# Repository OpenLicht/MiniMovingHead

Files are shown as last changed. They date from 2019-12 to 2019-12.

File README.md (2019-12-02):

# Moving Head

## Pinout

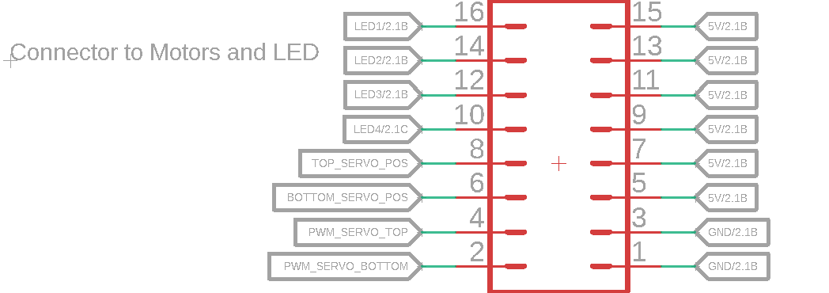
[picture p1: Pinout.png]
Pinout


## Protocol
Length is 3 bytes, command byte followed by two value bytes  
| command | value(high) | value(low)|

### Example
Set led_0 brightness to 100%  
Bytes to send: 0x70 0x00 0x64

## State select
|Command | State|
|---|---|
|0x91 | Manual movement|
|0x92 | Position regulation|

## Manual movement
|Command | Value | Action |
|---|---|---|
|0x41 | 0x00 | move bottom servo clockwise|
|0x42 | 0x00 | move bottom servo anticlockwise|
|0x45 | 0x01 ... 0x10 | set bottom servo speed [1 - 10]|
|0x51 | 0x00 | move top servo anticlockwise|
|0x52 | 0x00 | move top servo clockwise|
|0x70 | 0x00 ... 0x64 | set led_0 brightness [0 - 100 %]|
|0x71 | 0x00 ... 0x64 | set led_1 brightness [0 - 100 %]|
|0x72 | 0x00 ... 0x64 | set led_2 brightness [0 - 100 %]|
|0x73 | 0x00 ... 0x64 | set led_3 brightness [0 - 100 %]|
|0x90 | 0x00 | stop bottom servo|

## Position regulation
|Command | Value | Action|
|---|---|---|
|0x60 | 0x00 ... 0x168 | move bottom servo to position [0 - 360°]|
|0x61 | 0x00 ... 0xB4 | move top servo to position [0 - 180°]|
|0x70 | 0x00 ... 0x64 | set led_0 brightness [0 - 100 %]|
|0x71 | 0x00 ... 0x64 | set led_1 brightness [0 - 100 %]|
|0x72 | 0x00 ... 0x64 | set led_2 brightness [0 - 100 %]|
|0x73 | 0x00 ... 0x64 | set led_3 brightness [0 - 100 %]|

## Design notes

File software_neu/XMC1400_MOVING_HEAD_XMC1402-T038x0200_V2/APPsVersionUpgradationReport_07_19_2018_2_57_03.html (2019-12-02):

### DAVE CE Project Migration Report

#### APPs Upgrade to latest product version

Project name : XMC1400_MOVING_HEAD_XMC1402-T038x0200_0_Upgraded_0Date & Time : 07/19/2018 2:57 PM

Migration Log & Status

Project upgrade option will create a new project named with latest version of:

• APPs
• Startup folder
• Libraries folder
• linker_script.ld

All other settings and source files will be copied from this project

APPs Upgrade.. Started

Checking APP versions, found 5 APPs to migrate to higher versions

APPs Upgrade.. Completed

Getting solution from solver.. Successful

Code generation.. Successful

Build.. Successful

List of APPs
APP Name | | Message
CCU4_SLICE_CONFIG [v4.0.8] | Errors:0 Warnings:0 Info:0 | Higher version 4.0.16 found in Library store
CLOCK_XMC1 [v4.0.18] | Errors:0 Warnings:0 Info:0 | Higher version 4.0.20 found in Library store
CPU_CTRL_XMC1 [v4.0.6] | Errors:0 Warnings:0 Info:0 | Higher version 4.0.8 found in Library store
DIGITAL_IO [v4.0.16] | Errors:0 Warnings:0 Info:0 | No higher product version found in the Library store
GLOBAL_CCU4 [v4.1.12] | Errors:0 Warnings:0 Info:0 | No higher product version found in the Library store
GLOBAL_CCU8 [v4.1.12] | Errors:0 Warnings:0 Info:0 | No higher product version found in the Library store
I2C_MASTER [v4.1.18] | Errors:0 Warnings:0 Info:0 | Higher version 4.1.26 found in Library store
PWM [v4.1.10] | Errors:0 Warnings:0 Info:0 | No higher product version found in the Library store
UART [v4.1.8] | Errors:0 Warnings:0 Info:0 | Higher version 4.1.10 found in Library store

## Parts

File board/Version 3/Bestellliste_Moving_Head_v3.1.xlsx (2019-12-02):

Bauteile | Im Labor verfügbar? | Anzahl | Preis pro Stück | Kosten | Quelle |  | Nein
TPS71433DRVR | Nein | 1 | 0.648 | 0.6480 | https://www.mouser.de/ProductDetail/Texas-Instruments/TPS71433DRVR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 | 3.3V LDO U4 | Ja
GRM21B5C1H223FA01L 2,2nF/0,0022uF | Nein | 4 | 0.699 | 2.7960 | https://www.mouser.de/ProductDetail/Murata-Electronics/GRM21B5C1H223FA01L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 | C15,C17,C18,C19
C0805X225J4RECAUTO 2,2uF | Nein | 5 | 0.393 | 1.9650 | https://www.mouser.de/ProductDetail/KEMET/C0805X225J4RECAUTO | C2,C4,C6,C20,C7
C0805C475J9RACAUTO 4,7 uF | Nein | 1 | 0.402 | 0.4020 | https://www.mouser.de/ProductDetail/KEMET/C0805C475J9RACAUTO | C8 | Ja
:885012207098 100nF/0.1uF | Nein | 2 | 0.06 | 0.1200 | https://www.mouser.de/ProductDetail/Wurth-Electronics/885012207098 | C9,C10
CRL0805-JW-R300ELF 300 mOhm | Nein | 4 | 0.201 | 0.8040 | https://www.mouser.de/ProductDetail/Bourns/CRL0805-JW-R300ELF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 | R1,R2,R4,R8
BAT20JFILM dioden | Nein | 4 | 0.332 | 1.3280 | https://www.mouser.de/ProductDetail/STMicroelectronics/BAT20JFILM | D1,D3,D4,D5
24AA01T-I/OT | Nein | 1 | 0.18 | 0.1800 | https://www.mouser.de/ProductDetail/Microchip-Technology/24AA01T-I-OT?qs=JaP0%252bruNJH9QbK8hwgt6AQ== | EEPROM
105017-0001 USB Connector | Nein | 1 | 0.599 | 0.5990 | https://www.mouser.de/ProductDetail/Molex/105017-0001 | J1
20021111-00010T4LF Debug Connector | Nein | 2 | 0.533 | 1.0660 | https://www.mouser.de/ProductDetail/Amphenol-FCI/20021111-00010T4LF | J2
 | Nein |  |  | 0.0000 |  |  | Ja
LT3476EUHF#PBF LED TREIBER | Nein | 1 | 8.52 | 8.5200 | https://www.mouser.de/ProductDetail/Analog-Devices-Linear-Technology/LT3476EUHFPBF | LED Treiber
ERJ-PB3B4991V 4,99k ohm | Nein | 4 | 0.21 | 0.8400 | https://www.mouser.de/ProductDetail/Panasonic/ERJ-PB6B4991V | R9,R10,R11,R12
LG R971-KN-1 green | Nein | 1 | 0.096 | 0.0960 | https://www.mouser.de/ProductDetail/Inolux/IN-S85ATG | LED2
6ENF4422V 44.2kohm | Nein | 1 | 0.087 | 0.0870 | https://www.mouser.de/ProductDetail/Panasonic/ERJ-6ENF4422V | R13
ERJ-P6WF4701V | Nein | 2 | 0.484 | 0.9680 | https://www.mouser.de/ProductDetail/Panasonic/ERJ-P6WF4701V | R3
CRCW08050000Z0EAC 0 Ohm | Nein | 1 | 0.087 | 0.0870 | https://www.mouser.de/ProductDetail/Vishay/CRCW08050000Z0EAC | R16
CRCW080510K0FKEAC 10k Ohm | Nein | 2 | 0.046 | 0.0920 | https://www.mouser.de/ProductDetail/Vishay/CRCW080510K0FKEAC | R5/R6
ERJ-PB6B3302V 33k | Nein | 1 | 0.507 | 0.5070 | https://www.mouser.de/ProductDetail/Panasonic/ERJ-PB6B3302V | R7
F931C476MBAAJ6 | Nein | 1 | 0.599 | 0.5990 | https://www.mouser.de/ProductDetail/AVX/F931C476MBAAJ6 | C5 Tantalkondensator
KMR211GLFS | Nein | 1 | 0.296 | 0.2960 | https://www.mouser.de/ProductDetail/CK/KMR211GLFS | Taster
5V 2.1A Netzteil Power Adapter USB Charger EU Plug mit micro USB Kabel | Ja | 1 | 8.5 | Im Labor verfügbar | https://eckstein-shop.de/5V-21A-Netzteil-Power-Adapter-USB-Charger-EU-Plug-mit-micro-USB-Kabel | USB Netzteil
LZ2012M100WT - Hochfrequenzinduktivität, Oberflächenm., Baureihe MLZ, 10 µH, 350 mA, 0805 [Metrisch 2012] | Nein | 4 | 0.108 | 0.4320 | https://www.mouser.de/ProductDetail/TDK/MLZ2012M100WT000 | L3,L4,L5,L6
 | Nein |  |  | 0.0000
XMC1402T038X0200AAXUMA1 | Nein | 1 | 3.44 | 3.4400 | https://www.mouser.de/ProductDetail/Infineon/XMC1402T038X0200AAXUMA1/
BMD-340-A-R | Nein | 1 | 8.71 | 8.7100 | https://www.mouser.de/ProductDetail/Rigado/BMD-340-A-R
SML-H12V8TT86 | Nein | 1 | 0.428 | 0.4280 | https://www.mouser.de/ProductDetail/ROHM-Semiconductor/SML-H12V8TT86?qs=493kPxzlxfI59R5PYPQRxg%3D%3D
 | Ja |  |  | Im Labor verfügbar
 | Ja |  |  | Im Labor verfügbar
 | Ja |  |  | Im Labor verfügbar
ERJ-6ENF5100V 510 ohm | Nein | 1 | 0.087 | 0.0870 | https://www.mouser.de/ProductDetail/Panasonic-Industrial-Devices/ERJ-6ENF5100V | R17
ABM8W-20.0000MHZ-4-B1U-T3 | Nein | 1 | 0.525 | 0.5250 | https://www.mouser.de/ProductDetail/ABRACON/ABM8W-200000MHZ-4-B1U-T3/ | Quartz_µController
ABS07-32.768KHZ-7-T - Quarz, 32.768 kHz, SMD, 3.2mm x 1.5mm, 7 pF, 20 ppm, Baureihe ABS07 | Nein | 1 | 0.808 | 0.8080 | http://de.farnell.com/abracon/abs07-32-768khz-7-t/quarz-32-768khz-7pf-smd/dp/1838935?st=ABS07-32.768KHZ-7-T | Quartz_BLE
:885012107002 3,2uF | Nein | 1 | 0.175 | 0.1750 | https://www.mouser.de/ProductDetail/Wurth-Electronics/885012107002 | C1
08055A3R0KAT2A - 3pF - Quartz 32,… khz | Nein | 2 | 0.197 | 0.3940 | https://www.mouser.de/ProductDetail/AVX/08055A3R0KAT2A?qs=sGAEpiMZZMs0AnBnWHyRQKdiqyDPVQdAvr7kkMUBCe8%3d | C13,C14
08055A9R0JAT2A - 9pF Quarts 20Mhz | Nein | 2 | 0.197 | 0.3940 | https://www.mouser.de/ProductDetail/AVX/08055A9R0JAT2A?qs=sGAEpiMZZMs0AnBnWHyRQKdiqyDPVQdA0vVTcFIFIGI%3d | C27,C28
 | Ja |  |  | Im Labor verfügbar
AYZ0102AGRLC | Ja | 1 | 0.804 | Im Labor verfügbar | https://www.mouser.de/ProductDetail/CK/AYZ0102AGRLC
Gesamtkosten |  |  |  | 37.39

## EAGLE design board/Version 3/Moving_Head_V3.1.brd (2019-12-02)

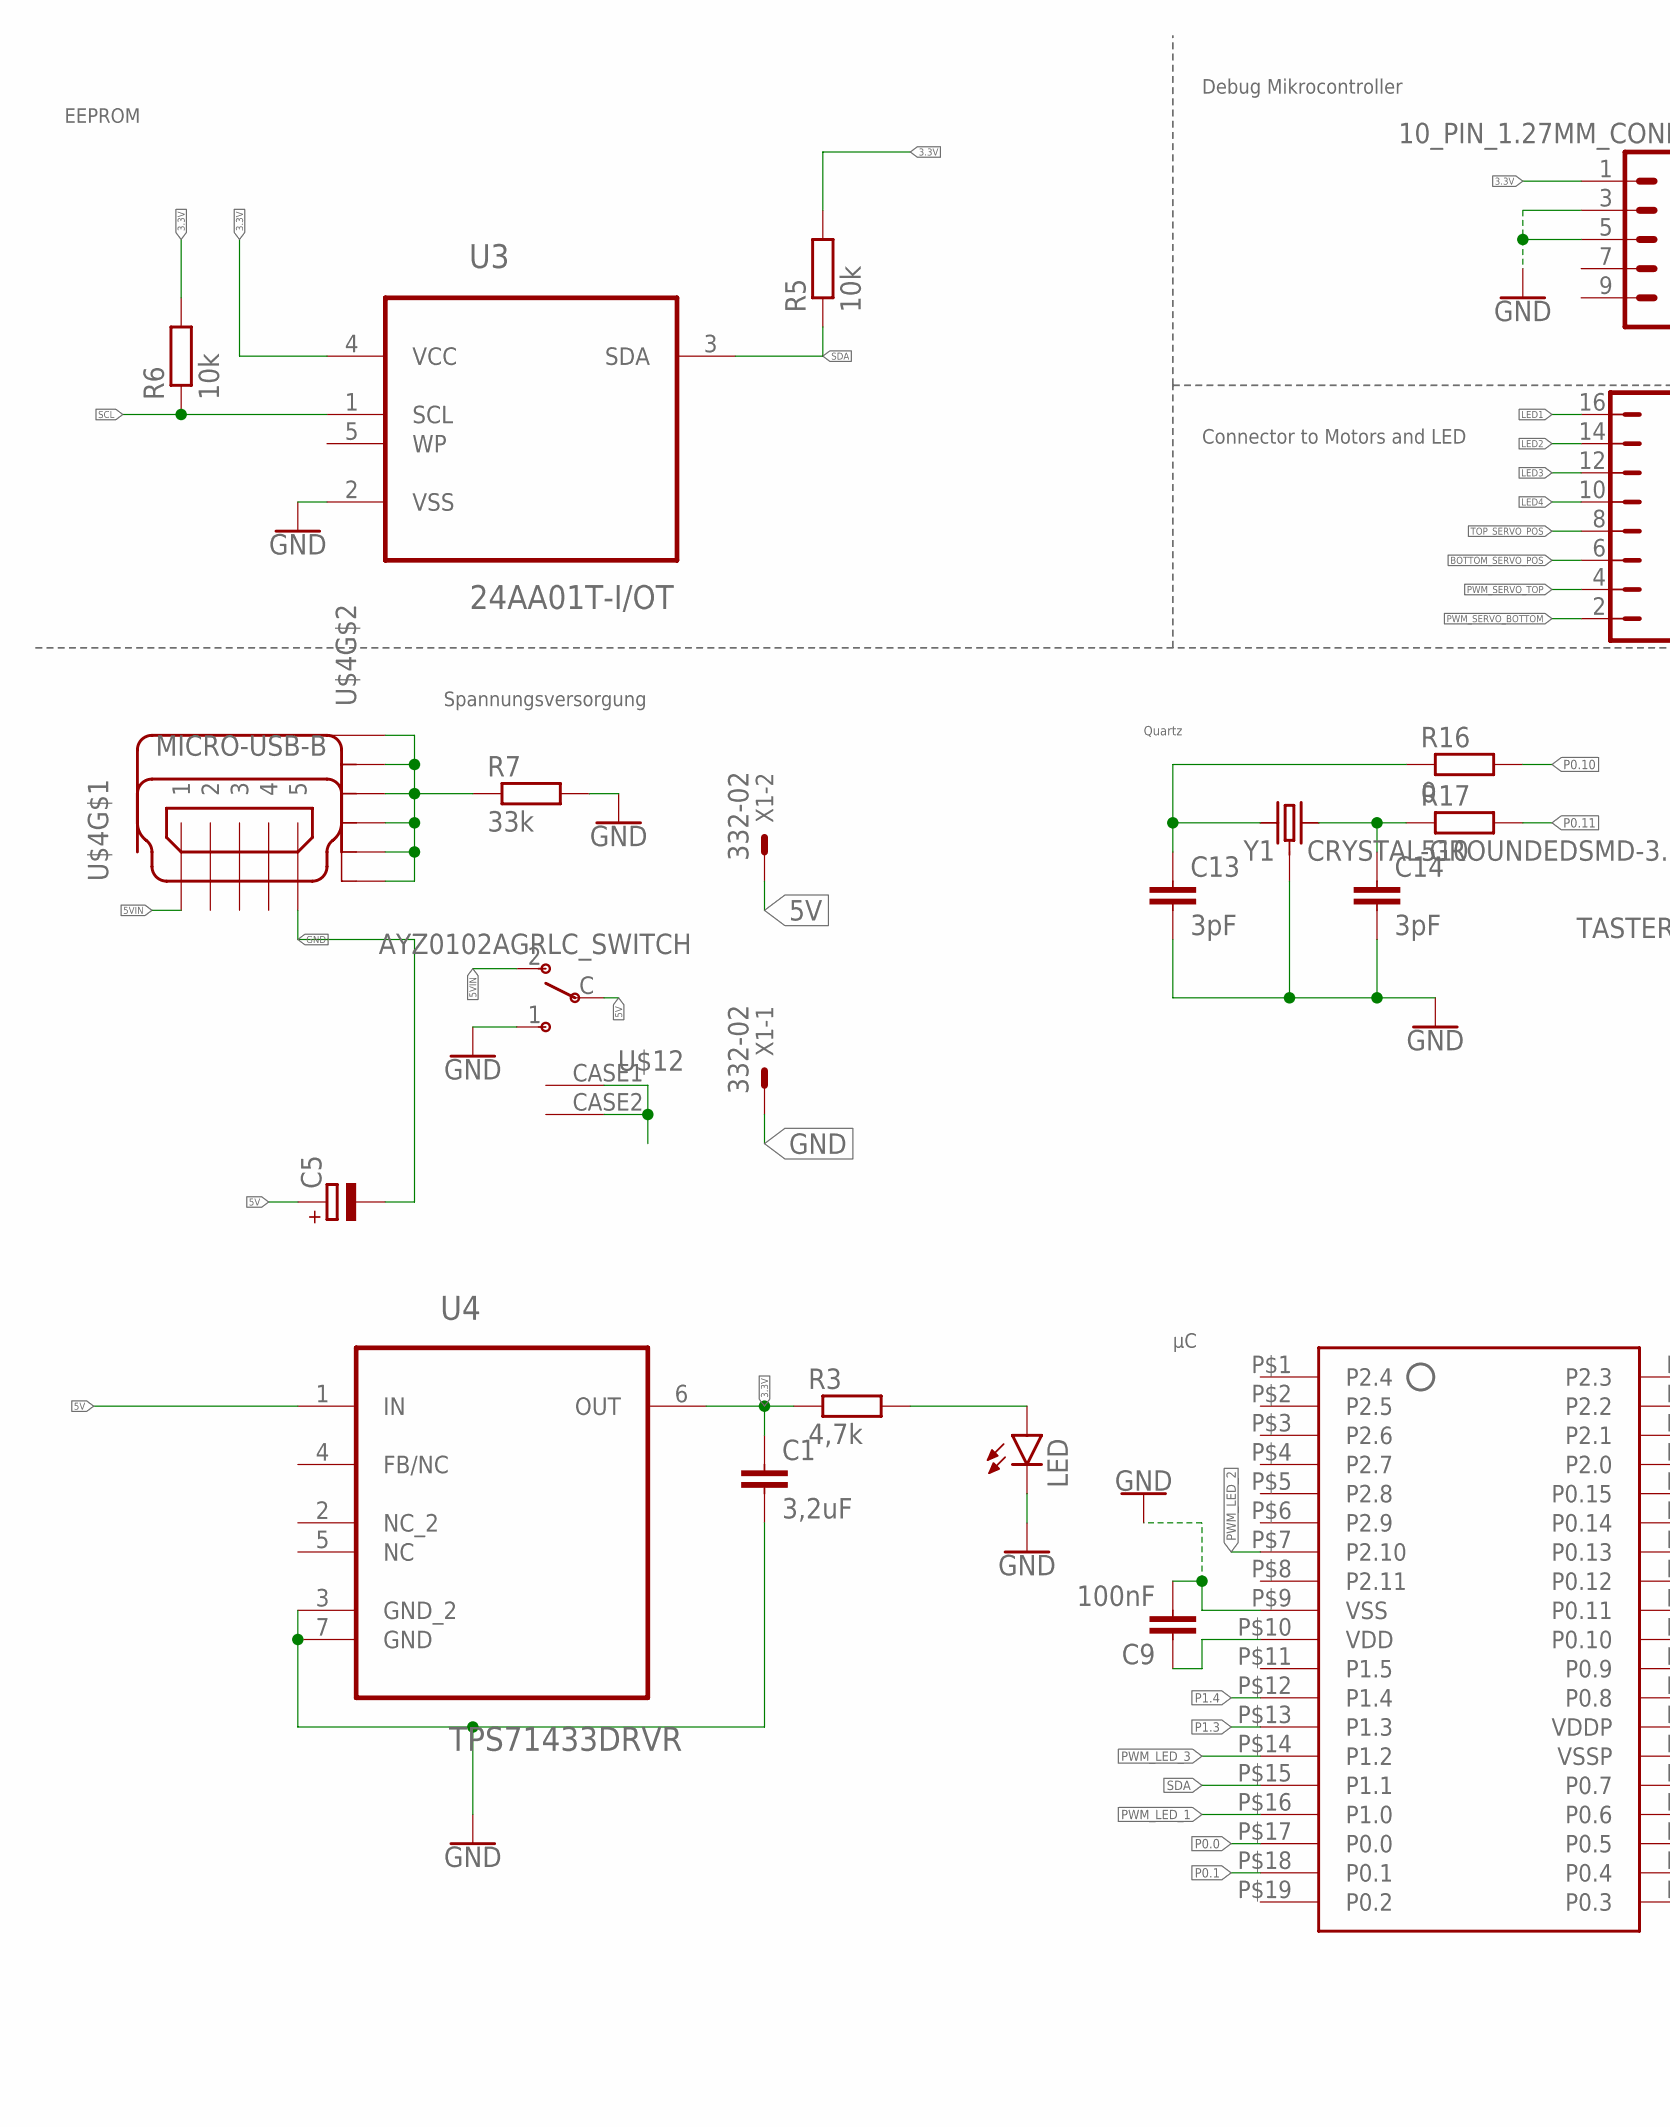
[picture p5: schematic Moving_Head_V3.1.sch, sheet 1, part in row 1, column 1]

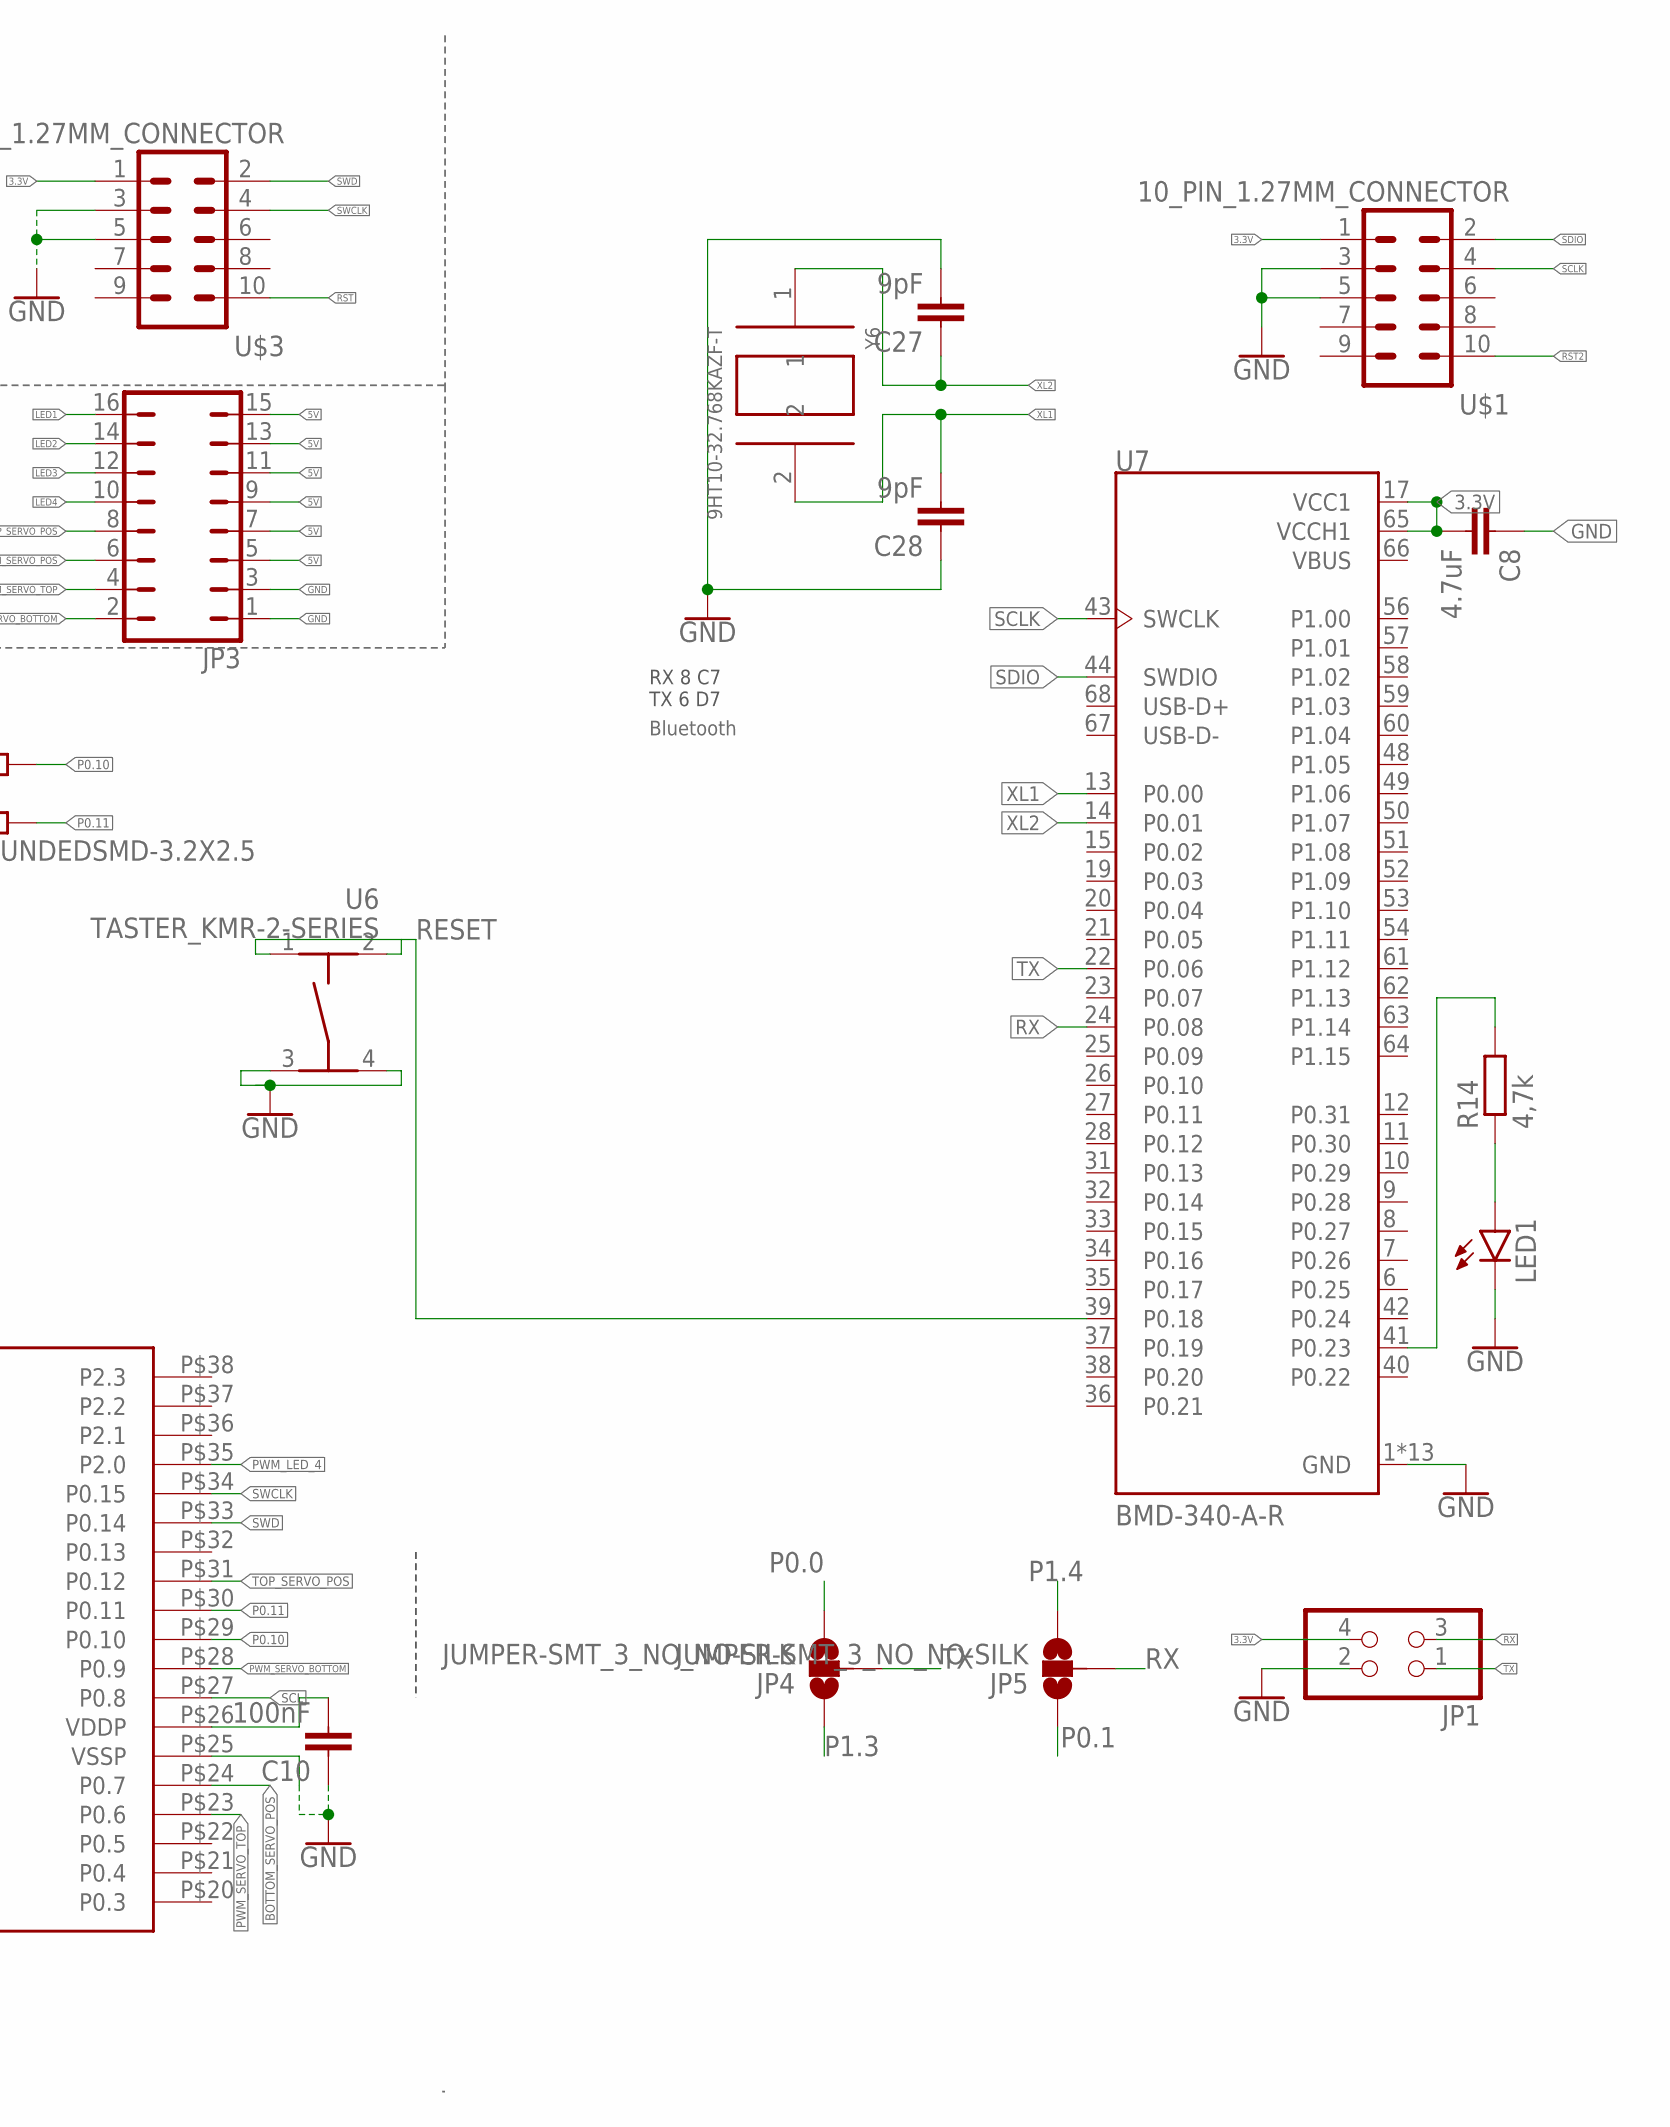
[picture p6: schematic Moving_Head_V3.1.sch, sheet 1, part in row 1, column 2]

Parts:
C1: 3,2uF; C0805
C5: CPOL-EUB/3528-21R; B/3528-21R
C8: 4.7uF; C0805
C9, C10: 100nF; C0805
C13, C14: 3pF; C0805
C27, C28: 9pF; C0805
JP1: PINHD-2X2; 2X02
JP3: JUMPER_JP8Q
JP4, JP5: JUMPER-SMT_3_NO_NO-SILK; SMT-JUMPER_3_NO_NO-SILK
LED: LEDCHIPLED_0805; CHIPLED_0805
LED1: SML-H12V8TT86; CHIPLED_0805
R3, R14: 4,7k; R0805
R5, R6: 10k; R0805
R7: 33k; R0805
R16: 0; R0805
R17: 510; R0805
U3: 24AA01T-I/OT; SOT95P270X145-5N
U4: TPS71433DRVR; SON65P200X200X80-7N
U5: XMC1400_38P
U6: TASTER_KMR-2-SERIES; KMR-2-SERIES
U7: BMD-340-A-R; RIGADO_BMD-340-A-R
U$1, U$3: 10_PIN_1.27MM_CONNECTOR; 10_PIN_1.27MM
U$4: MICRO-USB-B; MICRO_USB_B
U$12: AYZ0102AGRLC_SWITCH; AYZ0102AGRLC
X1: 332-02
Y1: CRYSTAL-GROUNDEDSMD-3.2X2.5; CRYSTAL-SMD-3.2X2.5MM
Y6: 9HT10-32.768KAZF-T; XTAL320X150X75

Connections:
3.3V: C1.1, C8.2, C9.1, C10.2, JP1.4, R3.1, R5.2, R6.2, U3.4 (VCC), U4.6 (OUT), U5.P$10 (VDD), U5.P$26 (VDDP), U7.17 (VCC1), U7.65 (VCCH1), U$1.1, U$3.1; also elsewhere on the board
5V: C5.+, JP3.5, JP3.7, JP3.9, JP3.11, JP3.13, JP3.15, U4.1 (IN), U$12.C, X1.2; also elsewhere on the board
5VIN: U$4.1, U$12.2
BOTTOM_SERVO_POS: JP3.6, U5.P$24 (P0.7)
GND: C1.2, C5.-, C8.1, C9.2, C10.1, C13.2, C14.2, C27.2, C28.1, JP1.2, JP3.1, JP3.3, LED.C, LED1.C, R7.2, U3.2 (VSS), U4.3 (GND_2), U4.7 (GND), U5.P$9 (VSS), U5.P$25 (VSSP), U6.3, U6.4, U7.1 (GND), U7.2 (GND), U7.3 (GND), U7.4 (GND), U7.5 (GND), U7.16 (GND), U7.18 (GND), U7.29 (GND), U7.30 (GND), U7.45 (GND), U7.46 (GND), U7.47 (GND), U7.55 (GND), U$1.3, U$1.5, U$3.3, U$3.5, U$4.5, U$12.1, U$12.CASE1, U$12.CASE2, X1.1, Y1.2 (3), Y1.4 (3); also elsewhere on the board
LED1: JP3.16; also elsewhere on the board
LED2: JP3.14; also elsewhere on the board
LED3: JP3.12; also elsewhere on the board
LED4: JP3.10; also elsewhere on the board
unnamed: R14.2, U7.41 (P0.23)
unnamed: LED1.A, R14.1
unnamed: LED.A, R3.2
unnamed: R7.1, U$4.P$1 (S1), U$4.P$2 (S2), U$4.P$6 (S3), U$4.P$7 (S4), U$4.P$9 (S5), U$4.P$10 (S6)
unnamed: C14.1, R17.1, Y1.3 (2)
unnamed: C13.1, R16.1, Y1.1
P0.0: JP4.3, U5.P$17 (P0.0)
P0.1: JP5.1, U5.P$18 (P0.1)
P0.10: R16.2, U5.P$29 (P0.10)
P0.11: R17.2, U5.P$30 (P0.11)
P1.3: JP4.1, U5.P$13 (P1.3)
P1.4: JP5.3, U5.P$12 (P1.4)
PWM_LED_1: U5.P$16 (P1.0); also elsewhere on the board
PWM_LED_2: U5.P$7 (P2.10); also elsewhere on the board
PWM_LED_3: U5.P$14 (P1.2); also elsewhere on the board
PWM_LED_4: U5.P$35 (P2.0); also elsewhere on the board
PWM_SERVO_BOTTOM: JP3.2, U5.P$28 (P0.9)
PWM_SERVO_TOP: JP3.4, U5.P$23 (P0.6)
RESET: U6.1, U6.2, U7.39 (P0.18)
RST: U$3.10
RST2: U$1.10
RX: JP1.3, JP5.2, U7.24 (P0.08)
SCL: R6.1, U3.1 (SCL), U5.P$27 (P0.8)
SCLK: U7.43 (SWCLK), U$1.4
SDA: R5.1, U3.3 (SDA), U5.P$15 (P1.1)
SDIO: U7.44 (SWDIO), U$1.2
SWCLK: U5.P$34 (P0.15), U$3.4
SWD: U5.P$33 (P0.14), U$3.2
TOP_SERVO_POS: JP3.8, U5.P$31 (P0.12)
TX: JP1.1, JP4.2, U7.22 (P0.06)
VBUS: U7.66 (VBUS)
XL1: C28.2, U7.13 (P0.00), Y6.2
XL2: C27.1, U7.14 (P0.01), Y6.1

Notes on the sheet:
Spannungsversorgung
Connector to Motors and LED
Debug Mikrocontroller
EEPROM
Quartz
Bluetooth
RX 8 C7 TX 6 D7

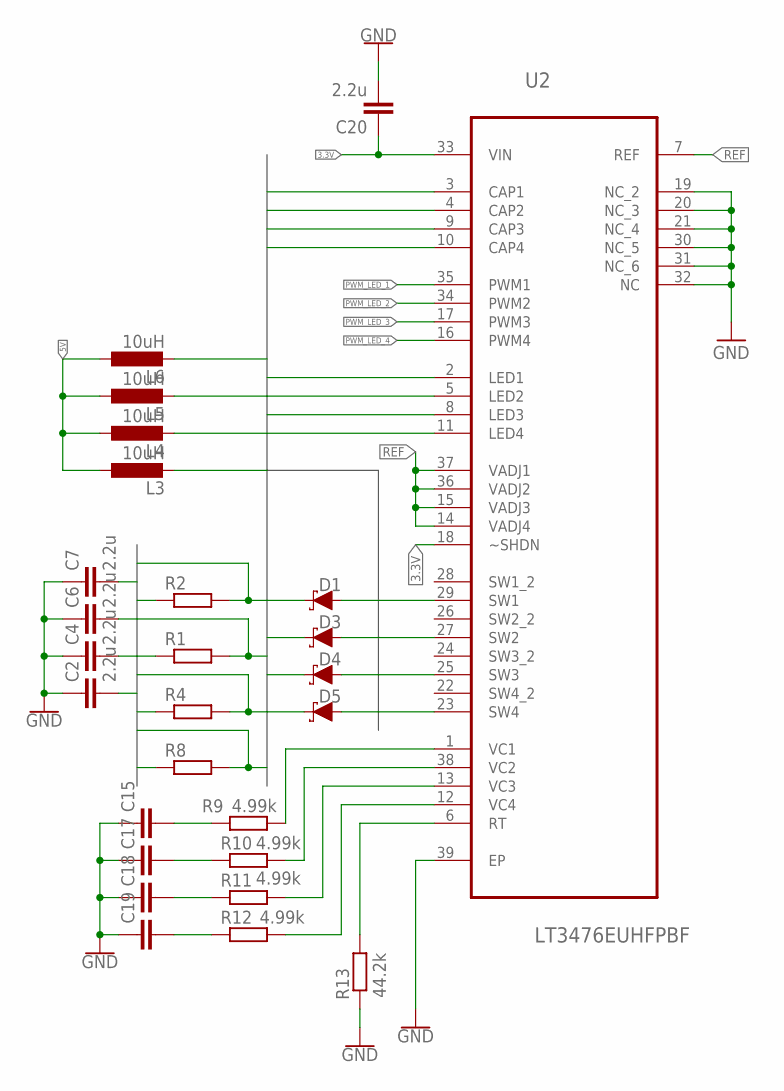
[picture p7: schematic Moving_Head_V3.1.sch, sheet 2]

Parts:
C2, C4, C6, C7, C20: 2.2u; C0805
C15, C17, C18, C19: 2.2n; C0805
D1, D3, D4, D5: 1A/23V/620mV; SOD-323
L3, L4, L5, L6: 10uH; L2012C
R1, R2, R4, R8: 300m; M0805
R9, R10, R11, R12: 4.99k; M0805
R13: 44.2k; M0805
U2: LT3476EUHFPBF; QFN50P500X700X80-39N

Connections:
3.3V: C20.1, U2.18 (~SHDN), U2.33 (VIN); also elsewhere on the board
5V: L3.1, L4.1, L5.1, L6.1; also elsewhere on the board
CAP1: C7.2, D1.C, R2.2, U2.3 (CAP1)
CAP2: C6.2, D3.C, R1.2, U2.4 (CAP2)
CAP3: C4.2, D4.C, R4.2, U2.9 (CAP3)
CAP4: C2.2, D5.C, R8.2, U2.10 (CAP4)
GND: C2.1, C4.1, C6.1, C7.1, C15.1, C17.1, C18.1, C19.1, C20.2, R13.1, U2.19 (NC_2), U2.20 (NC_3), U2.21 (NC_4), U2.30 (NC_5), U2.31 (NC_6), U2.32 (NC), U2.39 (EP); also elsewhere on the board
LED1: R2.1, U2.2 (LED1); also elsewhere on the board
LED2: R1.1, U2.5 (LED2); also elsewhere on the board
LED3: R4.1, U2.8 (LED3); also elsewhere on the board
LED4: R8.1, U2.11 (LED4); also elsewhere on the board
unnamed: R9.2, U2.1 (VC1)
unnamed: R10.2, U2.38 (VC2)
unnamed: R11.2, U2.13 (VC3)
unnamed: R12.2, U2.12 (VC4)
unnamed: R13.2, U2.6 (RT)
unnamed: C15.2, R9.1
unnamed: C17.2, R10.1
unnamed: C18.2, R11.1
unnamed: C19.2, R12.1
PWM_LED_1: U2.35 (PWM1); also elsewhere on the board
PWM_LED_2: U2.34 (PWM2); also elsewhere on the board
PWM_LED_3: U2.17 (PWM3); also elsewhere on the board
PWM_LED_4: U2.16 (PWM4); also elsewhere on the board
REF: U2.7 (REF), U2.14 (VADJ4), U2.15 (VADJ3), U2.36 (VADJ2), U2.37 (VADJ1)
SW1: D1.A, L6.2, U2.29 (SW1)
SW2: D3.A, L5.2, U2.27 (SW2)
SW3: D4.A, L4.2, U2.25 (SW3)
SW4: D5.A, L3.2, U2.23 (SW4)

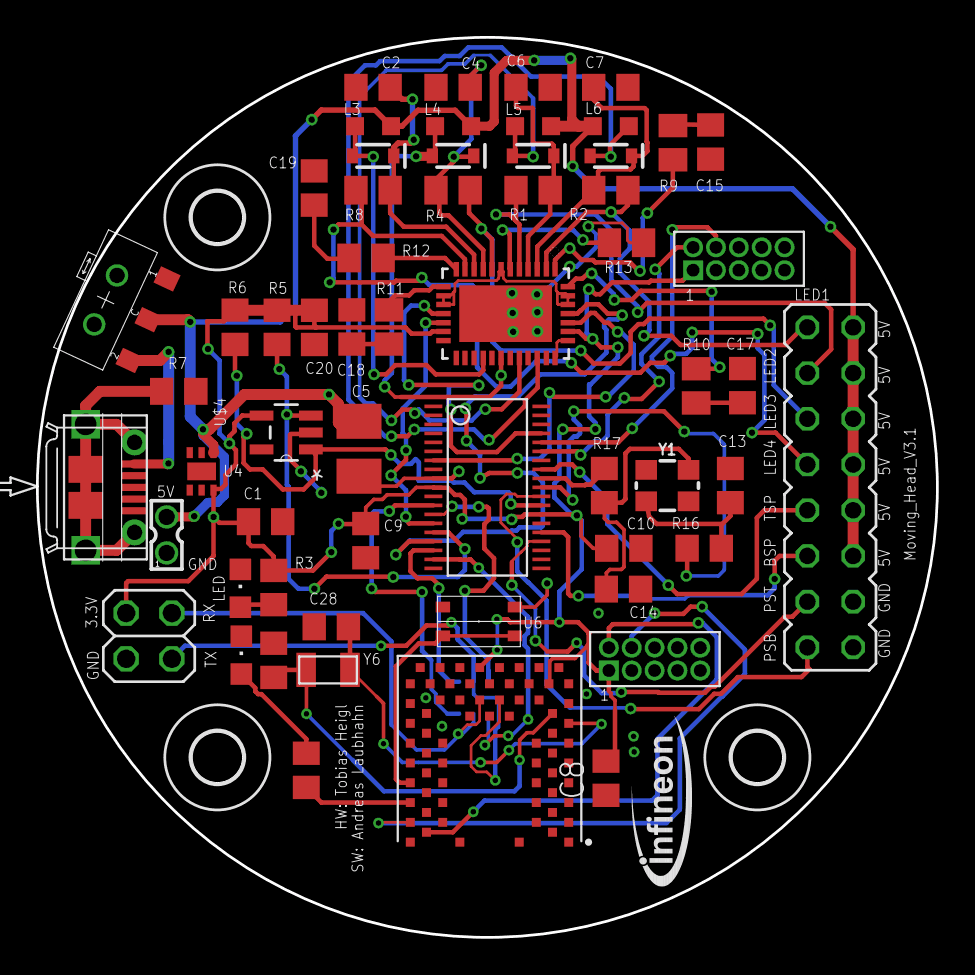
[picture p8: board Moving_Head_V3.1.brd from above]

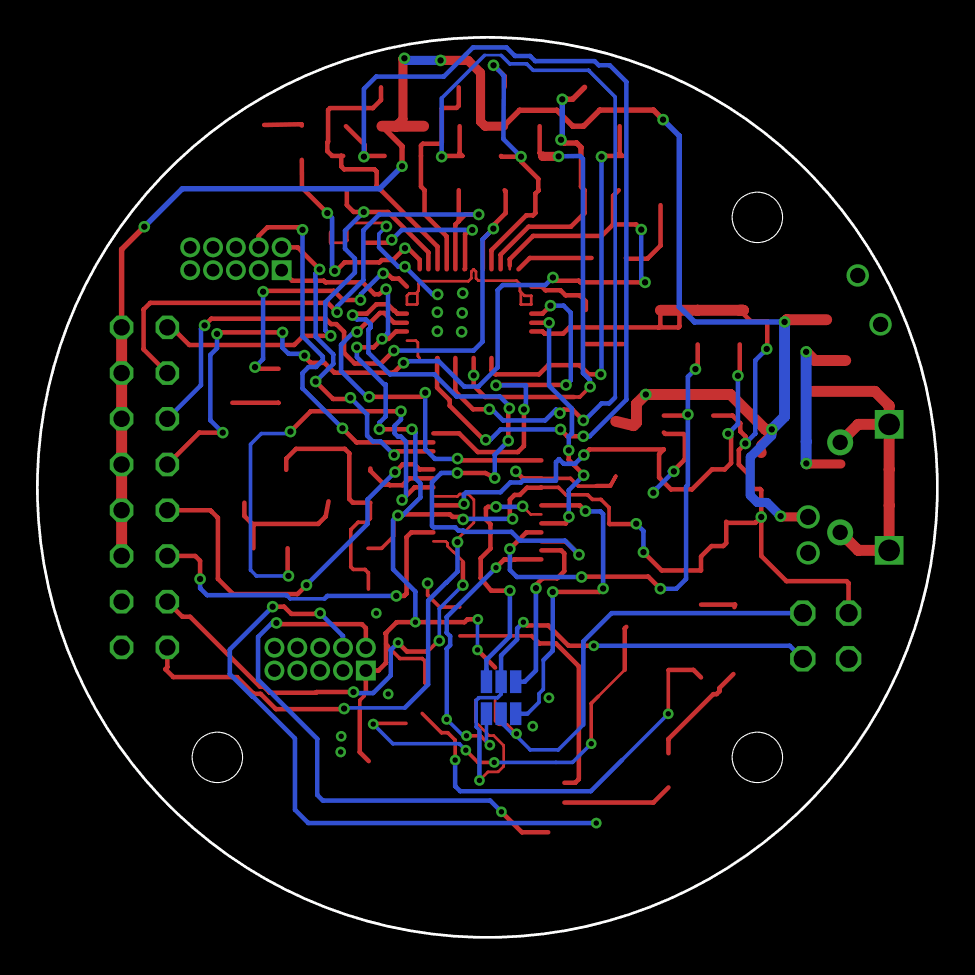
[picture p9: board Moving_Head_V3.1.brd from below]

Board: 2 copper layers, 50.0 x 50.0 mm, 64 parts (2 on the bottom side), 57 nets.

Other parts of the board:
U$5, U$6, U$8: 2,8

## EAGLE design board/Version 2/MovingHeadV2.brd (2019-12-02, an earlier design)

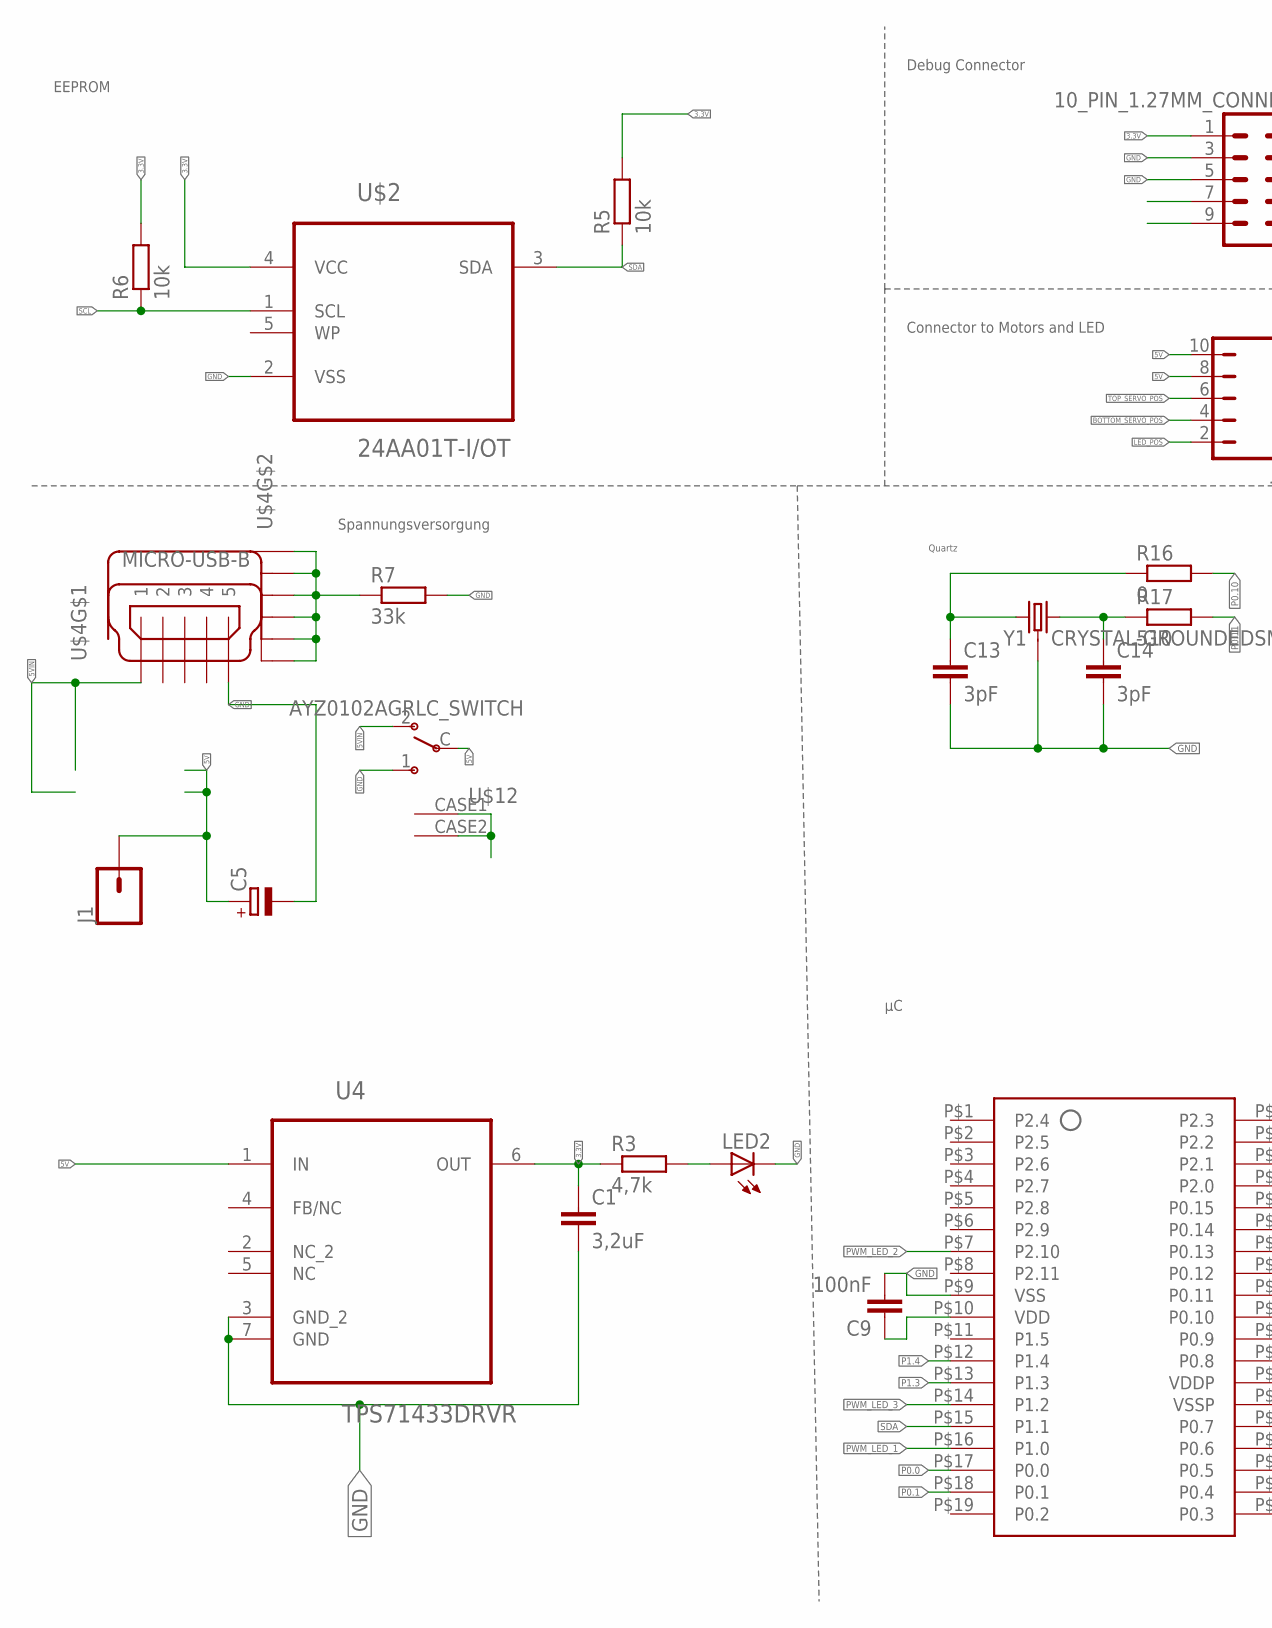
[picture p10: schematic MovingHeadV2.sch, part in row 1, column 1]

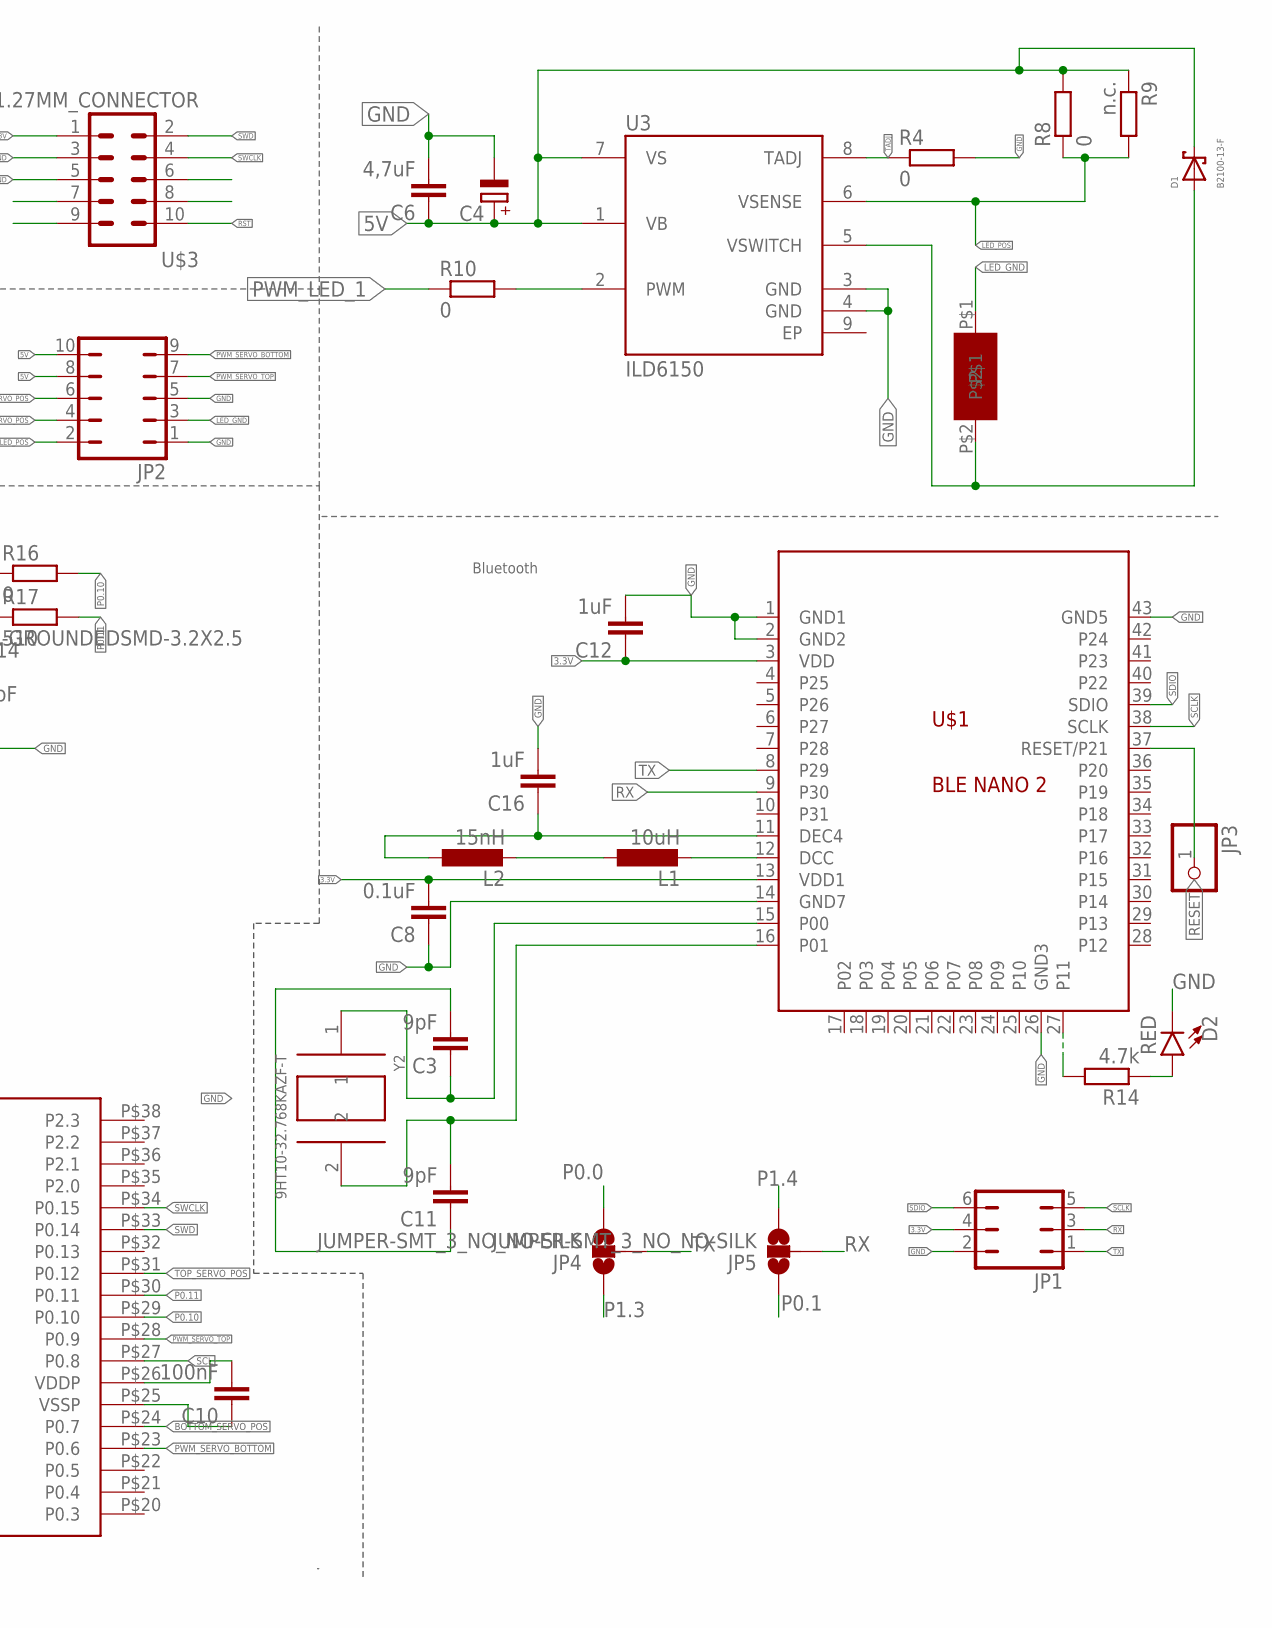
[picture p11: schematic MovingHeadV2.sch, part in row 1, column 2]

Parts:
C1: 3,2uF; C0805
C3, C11: 9pF; C0805
C4: CPOL-EUD; PANASONIC_D
C5: CPOL-EUB/3528-21R; B/3528-21R
C6: 4,7uF; C0805
C8: 0.1uF; C0805
C9, C10: 100nF; C0805
C12, C16: 1uF; C0603
C13, C14: 3pF; C0805
D1: B2100-13-F; SMB
D2: RED; LED-0603
J1: CONN_01; 1X01
JP1: JP3Q
JP2: JP5Q
JP3: PINHD-1X1; 1X01
JP4, JP5: JUMPER-SMT_3_NO_NO-SILK; SMT-JUMPER_3_NO_NO-SILK
L1: 10uH; L2012C
L2: 15nH; L2012C
LED2: LEDCHIPLED_0805; CHIPLED_0805
R3: 4,7k; R0805
R4, R8, R10, R16: 0; R0805
R5, R6: 10k; R0805
R7: 33k; R0805
R9: n.c.; R0805
R14: 4.7k; R0805
R17: 510; R0805
U3: ILD6150; SOIC127P600X170-9N-V2
U4: TPS71433DRVR; SON65P200X200X80-7N
U$1: BLE NANO 2; RBT07
U$2: 24AA01T-I/OT; SOT95P270X145-5N
U$3: 10_PIN_1.27MM_CONNECTOR; 10_PIN_1.27MM
U$4: MICRO-USB-B; MICRO_USB_B
U$7: CUSTOMCOIL6.8UH
U$10: XMC1400_38P
U$12: AYZ0102AGRLC_SWITCH; AYZ0102AGRLC
Y1: CRYSTAL-GROUNDEDSMD-3.2X2.5; CRYSTAL-SMD-3.2X2.5MM
Y2: 9HT10-32.768KAZF-T; XTAL320X150X75

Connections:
3.3V: C1.1, C8.2, C9.1, C10.2, C12.1, JP1.4, R3.1, R5.2, R6.2, U4.6 (OUT), U$1.3 (VDD), U$1.13 (VDD1), U$2.4 (VCC), U$3.1, U$10.P$10 (VDD), U$10.P$26 (VDDP)
5V: C4.+, C5.+, C6.1, D1.C, J1.1, JP2.8, JP2.10, R8.2, R9.1, U3.1 (VB), U3.7 (VS), U4.1 (IN), U$12.C
5VIN: U$4.1, U$12.2
BOTTOM_SERVO_POS: JP2.4, U$10.P$24 (P0.7)
EP: U3.9 (EP)
GND: C1.2, C3.2, C4.-, C5.-, C6.2, C8.1, C9.2, C10.1, C11.1, C12.2, C13.2, C14.2, C16.2, D2.C, JP1.2, JP2.1, JP2.5, LED2.C, R4.2, R7.2, U3.3 (GND), U3.4 (GND), U4.3 (GND_2), U4.7 (GND), U$1.1 (GND1), U$1.2 (GND2), U$1.14 (GND7), U$1.26 (GND3), U$1.43 (GND5), U$2.2 (VSS), U$3.3, U$3.5, U$4.5, U$10.P$9 (VSS), U$10.P$25 (VSSP), U$12.1, U$12.CASE1, U$12.CASE2, Y1.2 (3), Y1.4 (3)
LED_GND: JP2.3, U$7.P$1
LED_POS: JP2.2, R8.1, R9.2, U3.6 (VSENSE)
unnamed: R10.2, U3.2 (PWM)
unnamed: D2.A, R14.1
unnamed: LED2.A, R3.2
unnamed: R7.1, U$4.P$1 (S1), U$4.P$2 (S2), U$4.P$6 (S3), U$4.P$7 (S4), U$4.P$9 (S5), U$4.P$10 (S6)
unnamed: D1.A, U3.5 (VSWITCH), U$7.P$2
unnamed: C14.1, R17.1, Y1.3 (2)
unnamed: C13.1, R16.1, Y1.1
unnamed: L1.2, U$1.12 (DCC)
unnamed: L1.1, L2.2
unnamed: C16.1, L2.1, U$1.11 (DEC4)
unnamed: C3.1, U$1.15 (P00), Y2.1
unnamed: C11.2, U$1.16 (P01), Y2.2
unnamed: R14.2, U$1.27 (P11)
P0.0: JP4.3, U$10.P$17 (P0.0)
P0.1: JP5.1, U$10.P$18 (P0.1)
P0.10: R16.2, U$10.P$29 (P0.10)
P0.11: R17.2, U$10.P$30 (P0.11)
P1.3: JP4.1, U$10.P$13 (P1.3)
P1.4: JP5.3, U$10.P$12 (P1.4)
PWM_LED_1: R10.1, U$10.P$16 (P1.0)
PWM_LED_2: U$10.P$7 (P2.10)
PWM_LED_3: U$10.P$14 (P1.2)
PWM_SERVO_BOTTOM: JP2.9, U$10.P$23 (P0.6)
PWM_SERVO_TOP: JP2.7, U$10.P$28 (P0.9)
RESET: JP3.1, U$1.37 (RESET/P21)
RST: U$3.10
RX: JP1.3, JP5.2, U$1.9 (P30)
SCL: R6.1, U$2.1 (SCL), U$10.P$27 (P0.8)
SCLK: JP1.5, U$1.38 (SCLK)
SDA: R5.1, U$2.3 (SDA), U$10.P$15 (P1.1)
SDIO: JP1.6, U$1.39 (SDIO)
SWCLK: U$3.4, U$10.P$34 (P0.15)
SWD: U$3.2, U$10.P$33 (P0.14)
TADJ: R4.1, U3.8 (TADJ)
TOP_SERVO_POS: JP2.6, U$10.P$31 (P0.12)
TX: JP1.1, JP4.2, U$1.8 (P29)

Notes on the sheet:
Bluetooth
Spannungsversorgung
Connector to Motors and LED
Debug Connector
EEPROM
Quartz

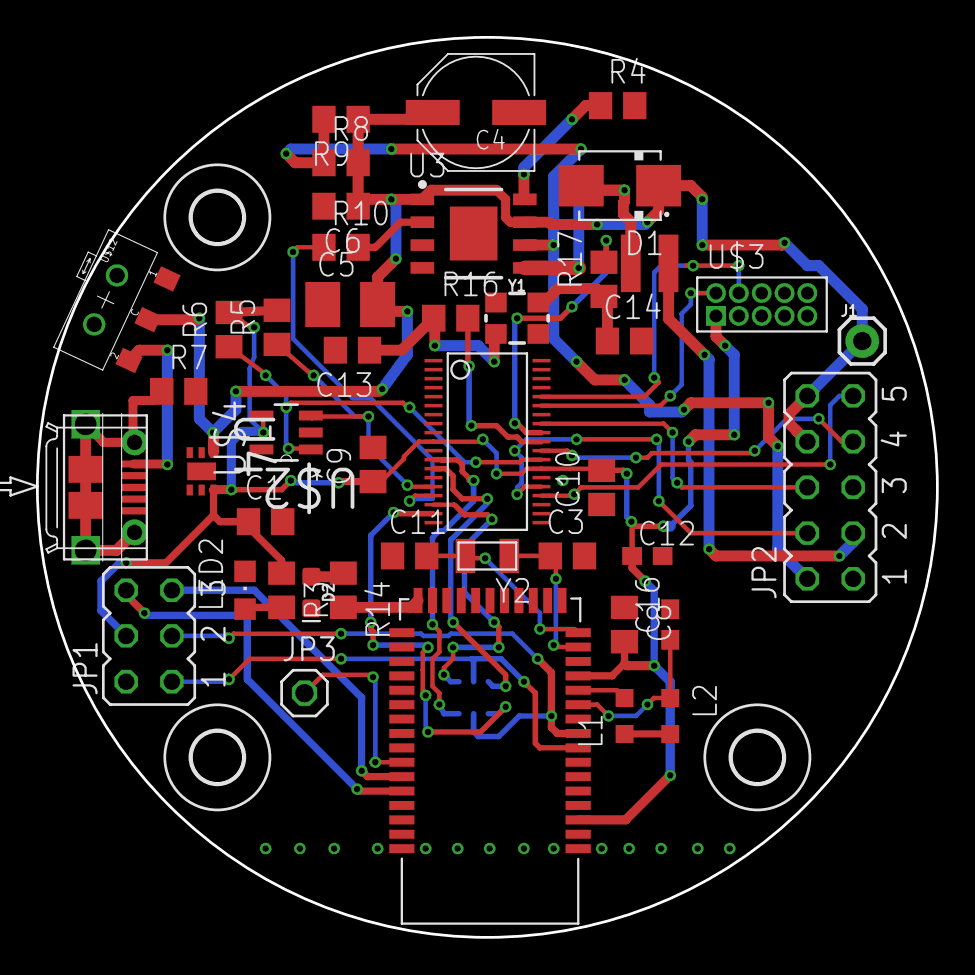
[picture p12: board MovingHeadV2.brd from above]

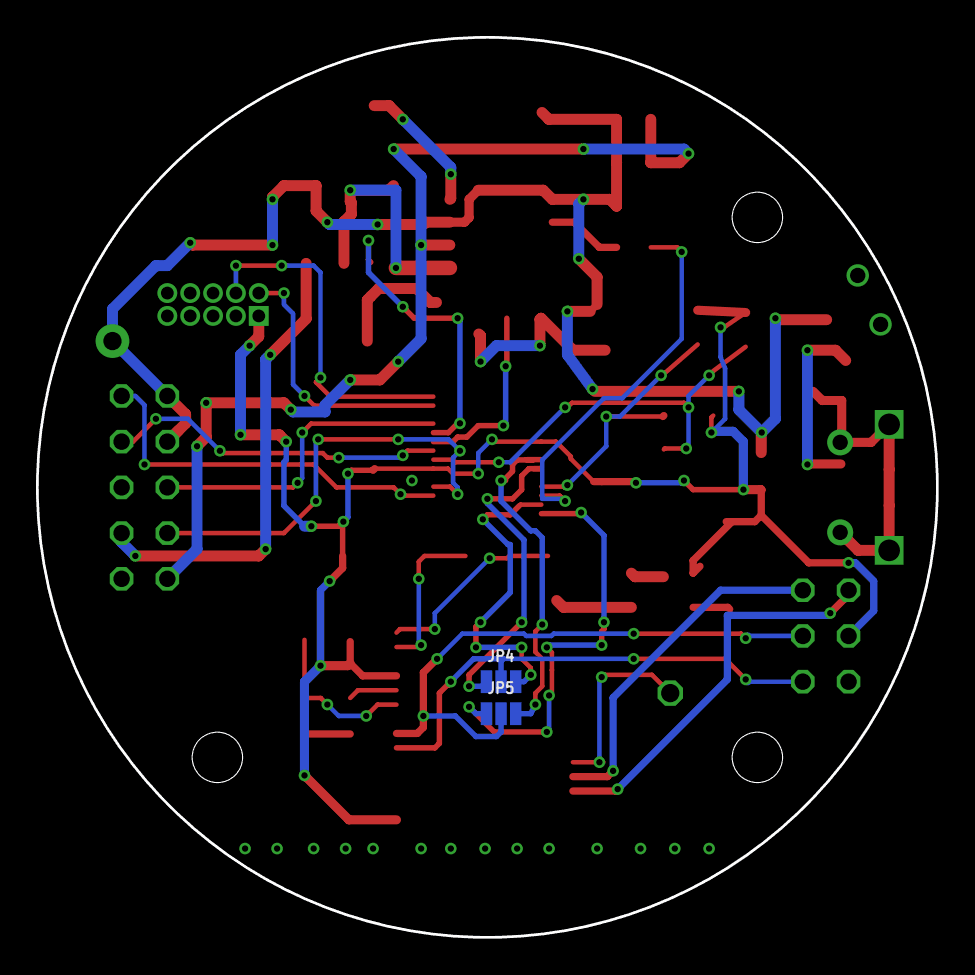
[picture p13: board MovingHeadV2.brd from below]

Board: 2 copper layers, 50.0 x 50.0 mm, 49 parts (2 on the bottom side), 40 nets.

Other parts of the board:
U$5, U$6, U$8: 2,8

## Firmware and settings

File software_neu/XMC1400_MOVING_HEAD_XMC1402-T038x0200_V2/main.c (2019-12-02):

#include <DAVE.h>                 //Declarations from DAVE Code Generation (includes SFR declaration)
#include "includes/my_fsm.h"

int main(void)
{
  DAVE_STATUS_t status;

  status = DAVE_Init();           /* Initialization of DAVE APPs  */

  state_t cur_state = MANUAL_MOVEMENT;
  if(status != DAVE_STATUS_SUCCESS)
  {
    /* Placeholder for error handler code. The while loop below can be replaced with an user error handler. */
    XMC_DEBUG("DAVE APPs initialization failed\n");

    while(1U)
    {

    }
  }
  /* Placeholder for user application code. The while loop below can be replaced with user application code. */
  PWM_SetDutyCycle(&PWM_LED_1, 0);
  while(1U)
  {
	  cur_state = run_state(cur_state);
  }
}

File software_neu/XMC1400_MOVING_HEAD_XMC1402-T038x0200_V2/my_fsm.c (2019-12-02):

#include <DAVE.h>
#include "includes/my_fsm.h"

static uint8_t bot_speed = 1;

state_func_t* const state_table[NUM_STATES] =
{
		position_detection, manual_movement
};

state_t run_state(state_t cur_state)
{
	return state_table[cur_state]();
}

void delay(uint32_t time)
{
	for(uint32_t i = 0; i < time; i++)
	{
		__asm("nop");
	}
}

static long map(long x, long in_min, long in_max, long out_min, long out_max)
{
	return(x - in_min) * (out_max - out_min) / (in_max - in_min) + out_min;
}

static void get_position(int *pos)
{
	uint16_t cycle = CCU40_CC41->CV[3];

	unsigned int time = 0.02 * cycle;

	// 0,0010989 --- 0.001099  || 1099 us => 100% 2,7% == 29 us, 97,1% == 1067 us
	// 0 - 360 angular position in units full circle = ((dc - dc_min) * 360) /(dc_max - dc_min + 1)

	int dc = 1000 * (time / 1099.0);
	*pos = (360 - 1) - ((dc - DC_MIN) * 360) / (DC_MAX - DC_MIN + 1); // (DC_MAX - DC_MIN + 1)
	if(*pos < 0) *pos = 0;
	else if(*pos > (360 - 1)) *pos = 360 - 1;
}

static int top_position = 0; // 750 <= get position from top servo

static void move_top_servo(int8_t offset)
{
	PWM_Start(&PWM_SERVO_TOP);
	while(msg[0] != 0x90)
	{
		UART_Receive(&UART_0, msg, 3);
		top_position += offset;
		if(top_position > 1100) top_position = 1100;
		if(top_position < 250) top_position = 250;
		PWM_SetDutyCycle(&PWM_SERVO_TOP, top_position);
		delay(80000); // 80000 adjust this value for a smooth rotation
	}
	PWM_Stop(&PWM_SERVO_TOP);
}

static void move_top_servo_to(int position)
{
	PWM_Start(&PWM_SERVO_TOP);
	PWM_SetDutyCycle(&PWM_SERVO_TOP, position);
	delay(1200000);
	PWM_Stop(&PWM_SERVO_TOP);
}

state_t position_detection()
{
	int position, top_pos;
	int pos = 0;
	int old_pos = 0, turns = 0, angle = 0, errorAng;
	int output, offset;
	uint32_t led_val;

	PWM_SetDutyCycle(&PWM_SERVO_BOTTOM, 730);
	while(1)
	{
		if(UART_Receive(&UART_0, msg, 3) == UART_STATUS_SUCCESS)
		{
			switch(msg[0])
			{
			case 0x60:
				pos = ((msg[1] << 8) | (msg[2] & 0xFF));
				pos = pos * 3;
				break;
			case 0x61:
				top_pos = ((msg[1] << 8) | (msg[2] & 0xFF));
				int map_pos = map(top_pos, 0, 180, 250, 1100);
				move_top_servo_to(map_pos);
				break;
			case 0x70:
				led_val = ((msg[1] << 8) | (msg[2] & 0xFF));
				int led_map = map(led_val, 0, 100, 0, 10000);
				PWM_SetDutyCycle(&PWM_LED_1, led_map);
				break;
			case 0x91:
				return MANUAL_MOVEMENT;
			}
		}

		get_position(&position);
		if(position < 90 && old_pos > 270)
		{
		  turns++;
		}
		else if(old_pos < 90 && position > 270)
		{
		  turns--;
		}
		if(turns >= 0) angle = (turns * 360) + position;
		else if(turns < 0) angle = ((turns + 1) * 360) - (360 - position);
		old_pos = position;

		errorAng = pos - angle;
		output = errorAng;
		if(output > 60) output = 60;
		if(output < -50) output = -50;
		if(errorAng > 0 ) offset = 10;
		else if(errorAng < 0) offset = -10;
		else offset = 0;
		PWM_SetDutyCycle(&PWM_SERVO_BOTTOM, 750 + output + offset);

		delay(240000);
	}
}

state_t manual_movement()
{
	uint32_t led_val;
	if(UART_Receive(&UART_0, msg, 3) == UART_STATUS_SUCCESS)
	{
		switch(msg[0])
		{
		case 0x41:
		  PWM_SetDutyCycle(&PWM_SERVO_BOTTOM, 750 + (bot_speed * 5) + 20);
		  break;
		case 0x42:
		  PWM_SetDutyCycle(&PWM_SERVO_BOTTOM, 750 - (bot_speed * 5) - 10);
		  break;
		case 0x45:
			bot_speed = msg[2];
			if(bot_speed > 10) bot_speed = 10;
			if(bot_speed < 1) bot_speed = 1;
			break;
		case 0x51:
		  move_top_servo(-10);
		  break;
		case 0x52:
		  move_top_servo(10);
		  break;
		case 0x70:
			led_val = ((msg[1] << 8) | (msg[2] & 0xFF));
			int led_map = map(led_val, 0, 100, 0, 10000);
			PWM_SetDutyCycle(&PWM_LED_1, led_map);
			break;
		case 0x90:
		  PWM_SetDutyCycle(&PWM_SERVO_BOTTOM, 750);
		  break;
		case 0x92:
			return POSITION_DETECTION;
		}
	}

	return MANUAL_MOVEMENT;
}

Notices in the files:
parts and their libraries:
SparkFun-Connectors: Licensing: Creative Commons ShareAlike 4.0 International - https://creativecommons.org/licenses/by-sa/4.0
